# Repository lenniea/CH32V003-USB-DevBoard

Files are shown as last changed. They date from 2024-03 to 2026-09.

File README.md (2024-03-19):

# CH32V003-USB-DevBoard




## Description

This is a CH32V003 USB-capable dev board (Prototype Stage).

It features:
* USB-C connector
* Optional Crystal
* User Button at PD7 (also for Reset)
* User LED at PC0
* USB (bit-bang) on PD3/PD4

## Sponsors

[AISLER](https://aisler.net/) is the sponsor for the prototypes and the first batch of PCBs!

You can get PCBs manufactured in two business days starting at just 10.16€.
Use the code `alexander_m` to get 5€ off your next order!

## Purchase

If you want to have some assembled boards, you can purchase them on [Lectronz](https://www.lectronz.com/products/ch32v003-usb-development-board)!

## Images

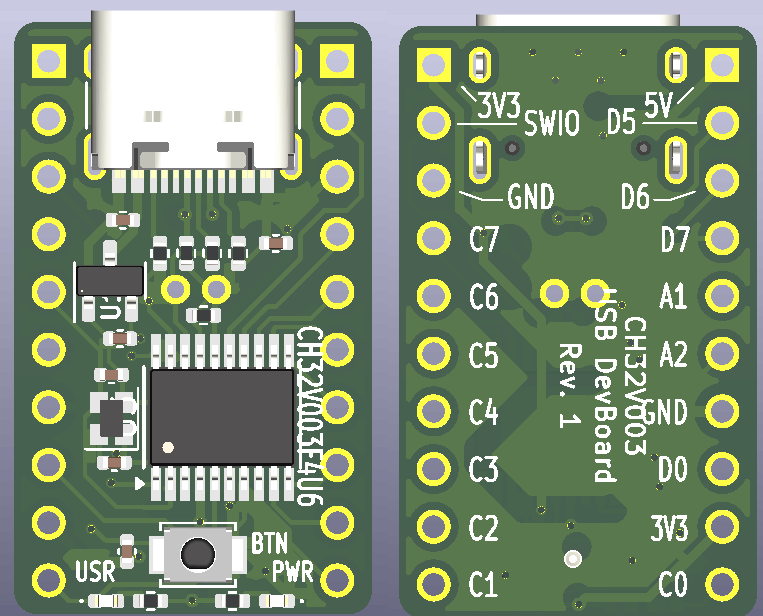
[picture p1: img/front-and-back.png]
Front and Back

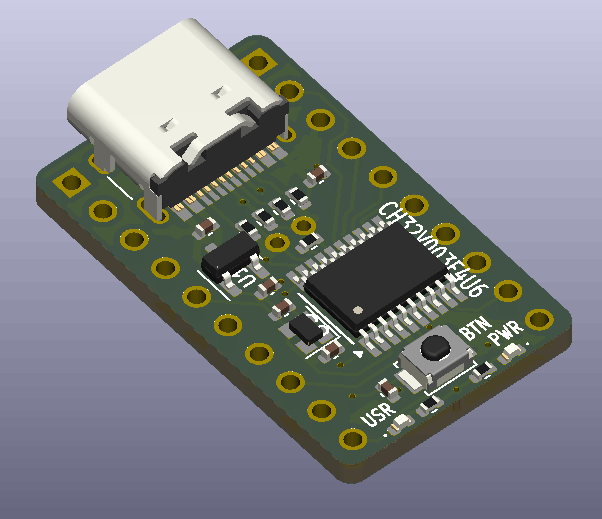
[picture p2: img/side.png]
Side


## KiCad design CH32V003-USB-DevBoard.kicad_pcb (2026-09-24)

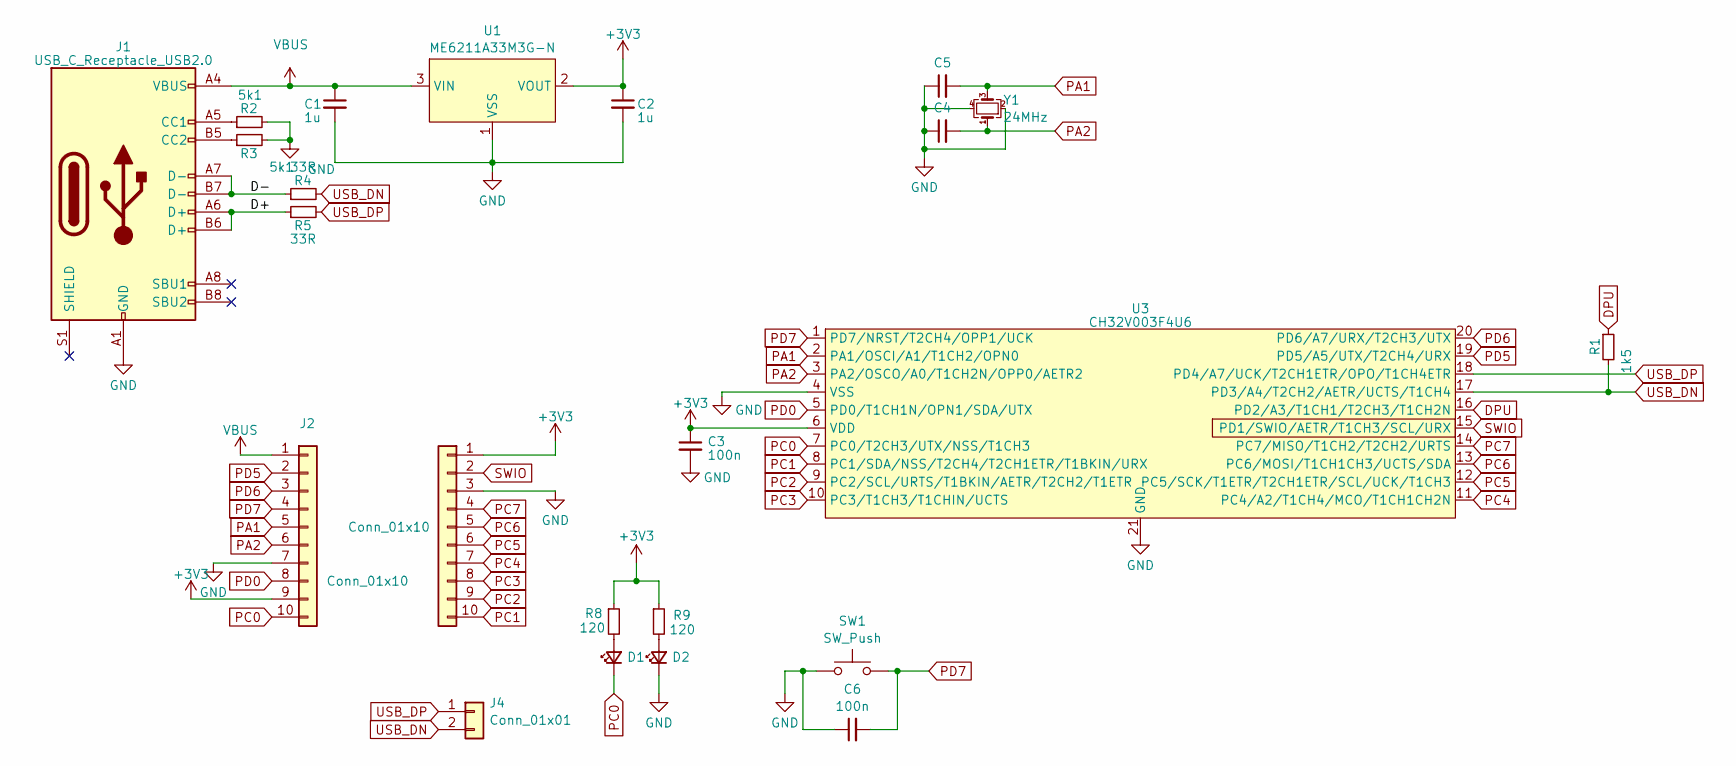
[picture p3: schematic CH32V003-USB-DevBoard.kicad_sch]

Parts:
C1, C2: 1u; C_0402_1005Metric; LCSC C52923
C3, C6: 100n; C_0402_1005Metric; LCSC C1525
C4, C5: 20p; C_0402_1005Metric; LCSC C882541
D1, D2: LED_Small; LED_0402_1005Metric; LCSC C5160702
J1: USB_C_Receptacle_USB2.0; USB_C_Receptacle_HRO_TYPE-C-31-M-12; LCSC C2927039
J2, J3: Conn_01x10; PinHeader_1x10_Small
J4: Conn_01x01; TestPoint_01x02
R1: 1k5; R_0402_1005Metric; LCSC C25867
R2, R3: 5k1; R_0402_1005Metric; LCSC C25905
R4, R5: 33R; R_0402_1005Metric; LCSC C25867
R8, R9: 120; R_0402_1005Metric; LCSC C25867
SW1: SW_Push; SW_SPST_B3U-1000P-B; LCSC C231329
U1: ME6211A33M3G-N; SOT-23-3; LCSC C168807
U3: CH32V003F4U6; ETSSOP-20-1EP_4.4x6.5mm_P0.65mm_EP3x4.2mm; LCSC C5299908
Y1: 24MHz; Crystal_SMD_2016-4Pin_2.0x1.6mm; LCSC C2875241

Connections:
+3V3: C2.1, C3.1, J2.9, J3.1, R8.1, R9.1, U1.2 (VOUT), U3.6 (VDD)
/D+: J1.A6 (D+), J1.B6 (D+), R5.1
/D-: J1.A7 (D-), J1.B7 (D-), R4.1
DPU: R1.1, U3.16 (PD2/A3/T1CH1/T2CH3/T1CH2N)
GND: C1.2, C2.2, C3.2, C4.1, C5.1, C6.1, D2.1 (K), J1.A1 (GND), J1.A12 (GND), J1.B1 (GND), J1.B12 (GND), J2.7, J3.3, R2.2, R3.2, SW1.1, U1.1 (VSS), U3.4 (VSS), U3.21 (GND), Y1.2, Y1.4
unnamed: D1.2 (A), R8.2
unnamed: D2.2 (A), R9.2
unnamed: J1.A5 (CC1), R2.1
unnamed: J1.B5 (CC2), R3.1
PA1: C5.2, J2.5, U3.2 (PA1/OSCI/A1/T1CH2/OPN0), Y1.3
PA2: C4.2, J2.6, U3.3 (PA2/OSCO/A0/T1CH2N/OPP0/AETR2), Y1.1
PC0: D1.1 (K), J2.10, U3.7 (PC0/T2CH3/UTX/NSS/T1CH3)
PC1: J3.10, U3.8 (PC1/SDA/NSS/T2CH4/T2CH1ETR/T1BKIN/URX)
PC2: J3.9, U3.9 (PC2/SCL/URTS/T1BKIN/AETR/T2CH2/T1ETR)
PC3: J3.8, U3.10 (PC3/T1CH3/T1CHIN/UCTS)
PC4: J3.7, U3.11 (PC4/A2/T1CH4/MCO/T1CH1CH2N)
PC5: J3.6, U3.12 (PC5/SCK/T1ETR/T2CH1ETR/SCL/UCK/T1CH3)
PC6: J3.5, U3.13 (PC6/MOSI/T1CH1CH3/UCTS/SDA)
PC7: J3.4, U3.14 (PC7/MISO/T1CH2/T2CH2/URTS)
PD0: J2.8, U3.5 (PD0/T1CH1N/OPN1/SDA/UTX)
PD5: J2.2, U3.19 (PD5/A5/UTX/T2CH4/URX)
PD6: J2.3, U3.20 (PD6/A7/URX/T2CH3/UTX)
PD7: C6.2, J2.4, SW1.2, U3.1 (PD7/NRST/T2CH4/OPP1/UCK)
SWIO: J3.2, U3.15 (PD1/SWIO/AETR/T1CH3/SCL/URX)
USB_DN: J4.2, R1.2, R4.2, U3.17 (PD3/A4/T2CH2/AETR/UCTS/T1CH4)
USB_DP: J4.1, R5.2, U3.18 (PD4/A7/UCK/T2CH1ETR/OPO/T1CH4ETR)
VBUS: C1.1, J1.A4 (VBUS), J1.A9 (VBUS), J1.B4 (VBUS), J1.B9 (VBUS), J2.1, U1.3 (VIN)

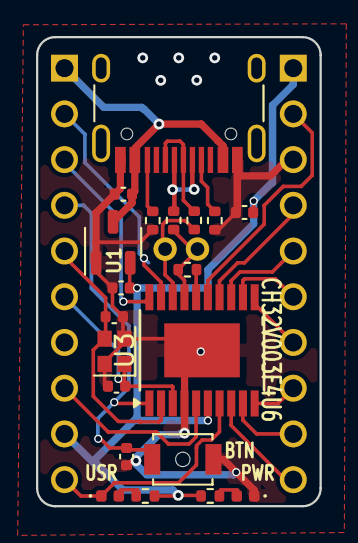
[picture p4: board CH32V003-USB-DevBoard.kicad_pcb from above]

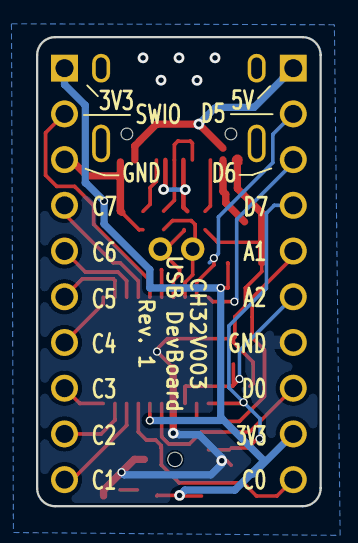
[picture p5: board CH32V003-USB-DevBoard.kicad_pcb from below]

Board: 2 copper layers, 15.8 x 26.1 mm, 23 parts (2 on the bottom side), 27 nets.

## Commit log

2026-09-24 Simplify design & switch to TSSOP-20 package for easier assembly
    [CH32V003-USB-DevBoard.kicad_pcb, CH32V003-USB-DevBoard.kicad_sch]
2026-09-24 Update board images
2026-09-24 Minor updates & cleanup
    [CH32V003-USB-DevBoard.kicad_pcb]
